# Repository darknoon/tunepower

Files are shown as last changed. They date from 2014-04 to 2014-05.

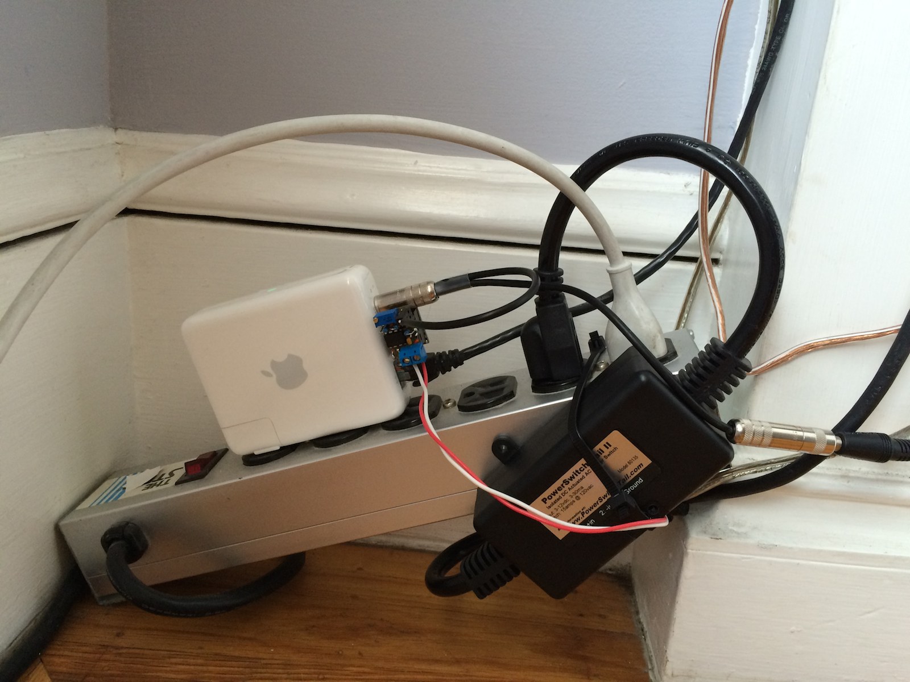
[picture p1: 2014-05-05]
readme-media/Installed_Downscaled.jpg

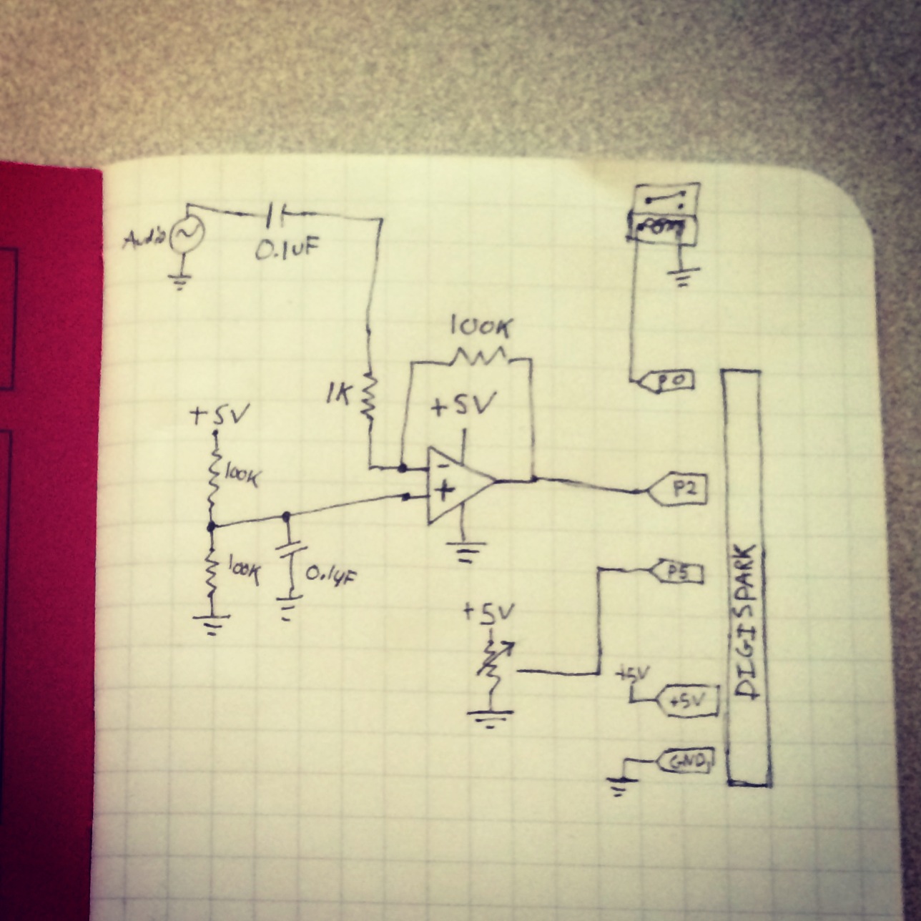
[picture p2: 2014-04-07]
readme-media/Schematic.JPG

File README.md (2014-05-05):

tunepower
=========

TunePower is a simple accessory for [Airport Express](https://www.apple.com/airport-express/) that automatically senses audio and turns on an accessory, namely an audio power amplifier. It is implemented with a [Digispark](http://digistump.com/products/1) microcontroller development board and a [PowerSwitch Tail II](http://www.powerswitchtail.com/Pages/default.aspx) relay to switch AC line voltage, as well as a small backpack board for the Digispark.

This system uses a simple LM741 op-amp circuit to amplify the audio for input into the [ATTiny85](http://www.atmel.com/devices/attiny85.aspx) microcontroller. The microcontroller manages turning on the relay circuit once an audio signal is detected. The software keeps the output on for a period of at least 10 minutes, to avoid rapid cycling of power amplifier.

Future enhancements:
One future feature that could increase reliability is to implement software such that when the circuit shuts off, a lockout period of 1 second is enforced. This will make sure any transients introduced in an AC line voltage transition do not reactivate the detector.

Pictures below:
1. Original prototype under development.
2. Digispark + backpack front view.
3. Digispark + backpack back view.







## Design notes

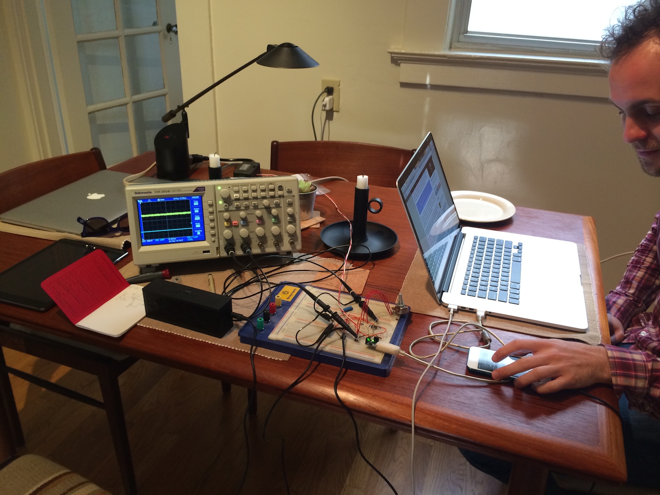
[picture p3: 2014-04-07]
readme-media/Breadboard_Prototype.JPG

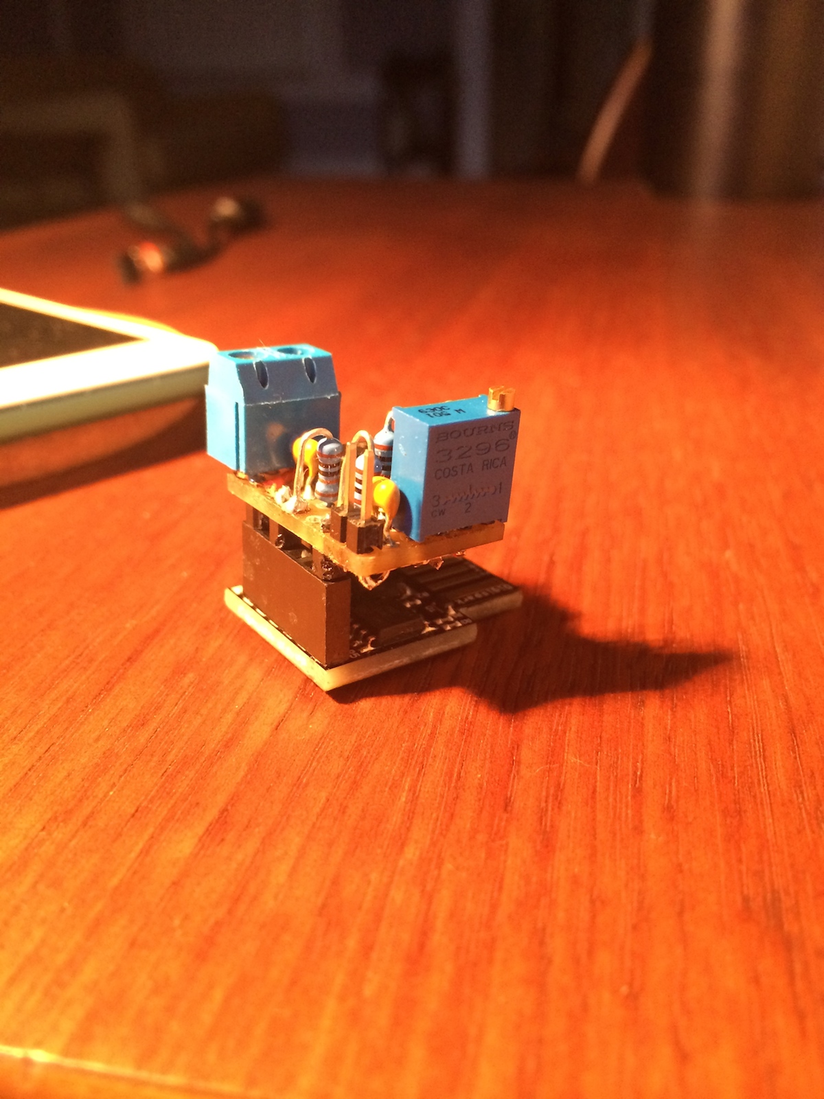
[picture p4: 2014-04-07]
readme-media/Digispark_back.jpg

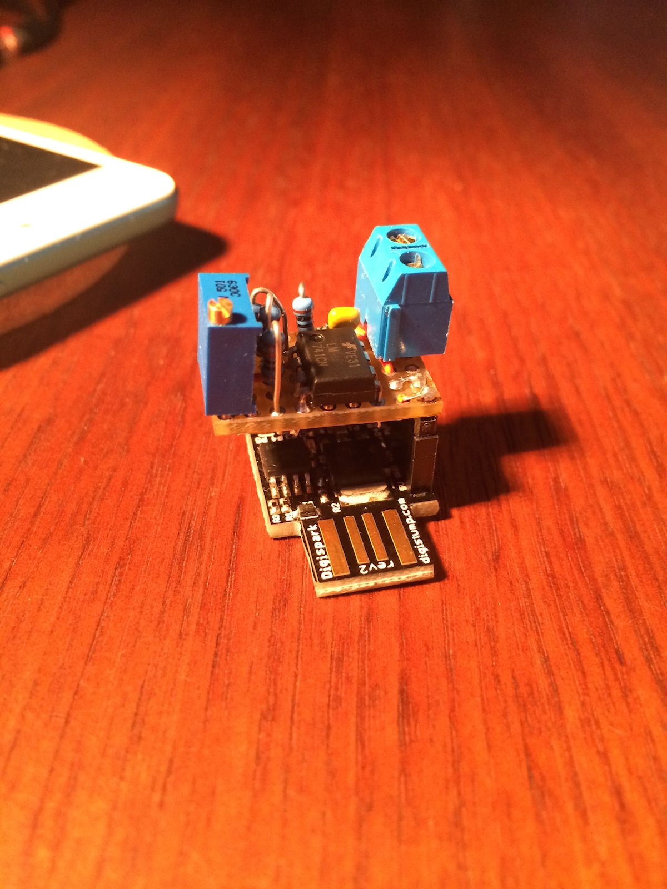
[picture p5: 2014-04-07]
readme-media/Digispark_front_Downscaled.jpg

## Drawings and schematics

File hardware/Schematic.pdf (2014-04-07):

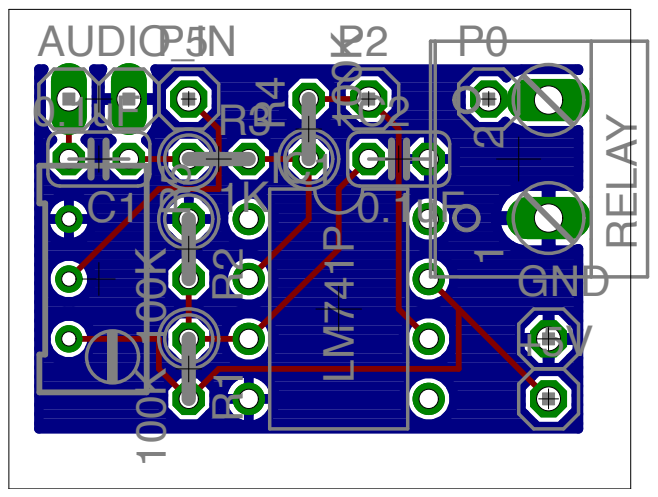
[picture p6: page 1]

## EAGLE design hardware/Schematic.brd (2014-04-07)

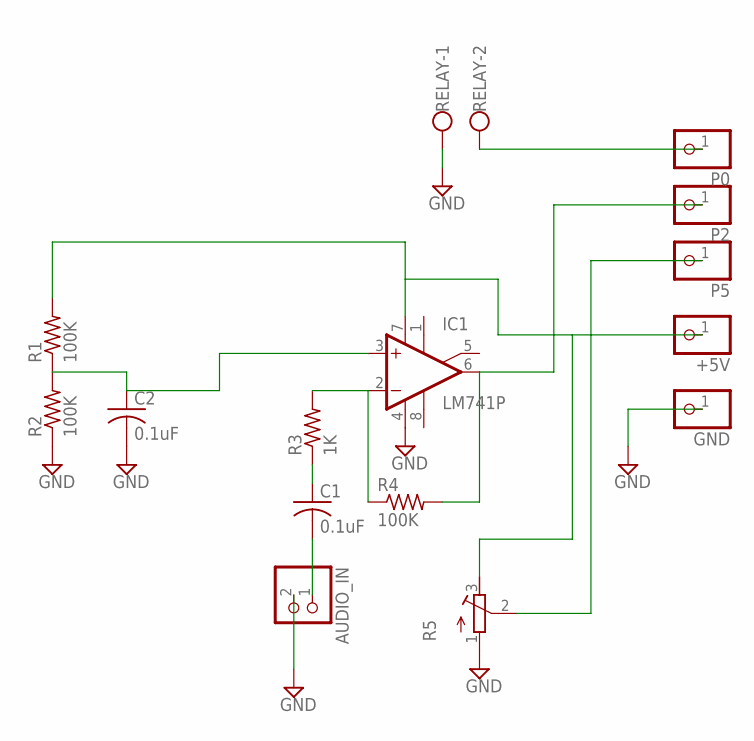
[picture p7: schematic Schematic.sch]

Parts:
+5V: PINHD-1X1; 1X01
AUDIO_IN: PINHD-1X2; 1X02
C1, C2: 0.1uF; C025-024X044
GND: PINHD-1X1; 1X01
IC1: LM741P; DIL08
P0, P2, P5: PINHD-1X1; 1X01
R1, R2, R4: 100K; 0207/2V
R3: 1K; 0207/2V
R5: R-TRIMM64W; RTRIM64W
RELAY: W237-102

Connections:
GND: AUDIO_IN.2, C2.2, GND.1, IC1.4 (V-), R2.1, R5.1 (E), RELAY.1
unnamed: C1.1, R3.1
unnamed: C2.1, IC1.3 (+IN), R1.1, R2.2
unnamed: AUDIO_IN.1, C1.2
unnamed: IC1.2 (-IN), R3.2, R4.1
unnamed: IC1.6 (OUT), P2.1, R4.2
unnamed: +5V.1, IC1.7 (V+), R1.2, R5.3 (A)
unnamed: P0.1, RELAY.2
unnamed: P5.1, R5.2 (S)

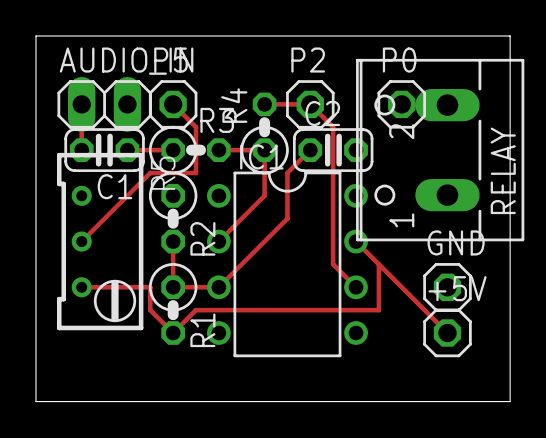
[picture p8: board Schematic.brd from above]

Board: 2 copper layers, 26.3 x 20.3 mm, 15 parts (0 on the bottom side), 9 nets.

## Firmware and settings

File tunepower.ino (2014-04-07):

int16_t LED_BUILTIN = 1;  //LED on Model A  

int16_t DIGITAL_OUT_PIN = 0;

int16_t AUDIO_IN_PIN = 2;
int16_t AUDIO_IN_ANALOG = 1;

int16_t AMP_IN_PIN = 5;
int16_t AMP_IN_ANALOG = 0;

int16_t MAX_READ = 1024;
int16_t MAX_WRITE = 255;

// the setup routine runs once when you press reset:
void setup() {
  pinMode(DIGITAL_OUT_PIN, OUTPUT);
  pinMode(LED_BUILTIN, OUTPUT); 
  pinMode(AUDIO_IN_PIN, INPUT);
  pinMode(AMP_IN_PIN, INPUT);
}

float signal = 0.0;
float reference = 0.5;

float k_ref = 0.999;
float k = 0.999;

// End of the current time cycle (52 days)
uint32_t END_OF_TIME = (uint32_t)(-1);
uint32_t SECOND = 1000;
uint32_t DEBUG_SHUTOFF_START = 1 * SECOND;
//uint32_t SHUTOFF_INTERVAL = 60*60*1000;
uint32_t SHUTOFF_INTERVAL = 10*SECOND;

bool isOn = false;
bool shutting_off = false;
uint32_t time_prev = 0;
uint32_t turnoff_time = END_OF_TIME;

#define STATIC_ASSERT(COND,MSG) typedef char static_assertion_##MSG[(COND)?1:-1]

STATIC_ASSERT(sizeof(char) == 1, size_of_char);
STATIC_ASSERT(sizeof(int) == 2, size_of_int);
STATIC_ASSERT(sizeof(unsigned long) == 4, size_of_unsigned_long);
STATIC_ASSERT(sizeof(long) == 4, size_of_long);
STATIC_ASSERT(sizeof(long long) == 8, size_of_long_long);
STATIC_ASSERT(sizeof(float) == 4, size_of_float);

// Returns 1 if the output should be on
bool doTimer(bool signal) {
  bool nextOn = isOn;
  // Process timer
  uint32_t time = millis();
  // Handle time overflow
  if (time < time_prev) {
    turnoff_time = time + SHUTOFF_INTERVAL;
    time_prev = 0;
  }

  if (signal) {
    turnoff_time = time + SHUTOFF_INTERVAL;
    shutting_off = false;
    nextOn = true;
  } else if (isOn && time > turnoff_time)  {
    shutting_off = false;
    nextOn = false;
    turnoff_time = 0;
  } else if (isOn && time > turnoff_time - (SHUTOFF_INTERVAL - DEBUG_SHUTOFF_START) ) {
    shutting_off = true;
    nextOn = true;
  } else {
    shutting_off = false;
    nextOn = isOn;
  }

  time_prev = time;
  isOn = nextOn;
  return nextOn;
}

// the loop routine runs over and over again forever:
void loop() {

  // Potentiometer to set gain
  float gainKnob = analogRead(AMP_IN_ANALOG) / (float)(MAX_READ);
  float gain = exp(10.0 * gainKnob); // map the volume knob exponentially from 1 to 22026

  float rawAudio = analogRead(AUDIO_IN_ANALOG) / (float)(MAX_READ);

  // Audio is the difference between raw input and the reference voltage
  float audio = rawAudio - reference;

  // Auto adjust the reference for any bias in center voltage
  reference = k_ref * reference + (1.0 - k_ref) * rawAudio;

  // How much power there was at this instant
  float instPower = sqrt(audio * audio);
  signal = k * signal + (1.0 - k) * instPower;

  digitalWrite(LED_BUILTIN, shutting_off ? HIGH : LOW);

  bool detected = signal * gain > 1.0;
  bool on = doTimer(detected);

  digitalWrite(DIGITAL_OUT_PIN, on ? HIGH : LOW);
}

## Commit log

2014-04-07 Adding Eagle schematic and board documents for Digispark backpack.
    [Schematic.brd, Schematic.sch]
2014-04-07 Adding schematic to readme.
